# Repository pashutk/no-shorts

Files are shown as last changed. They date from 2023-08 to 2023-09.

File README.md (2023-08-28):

# USB-C Soldering Inspection Hat for Pi Pico

This repository contains a KiCad project for a Raspberry Pi Pico hat. The primary function of this device is to aid in the assessment of soldered USB-C connectors by identifying potential shorts. It offers a practical solution for those requiring a methodical approach to verify the integrity of their soldered USB-C connections.



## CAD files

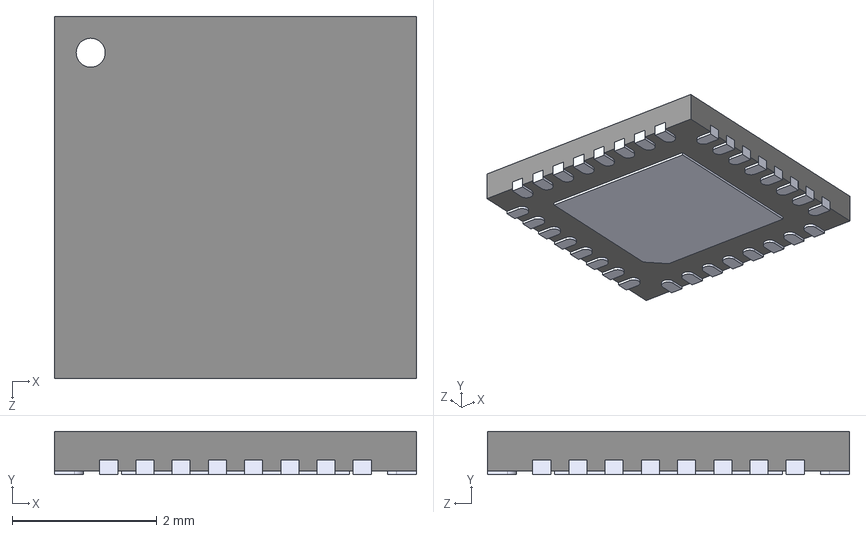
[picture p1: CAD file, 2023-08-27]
3d/TCA6424ARGJR.step
5.00 x 0.6 x 5.00 mm

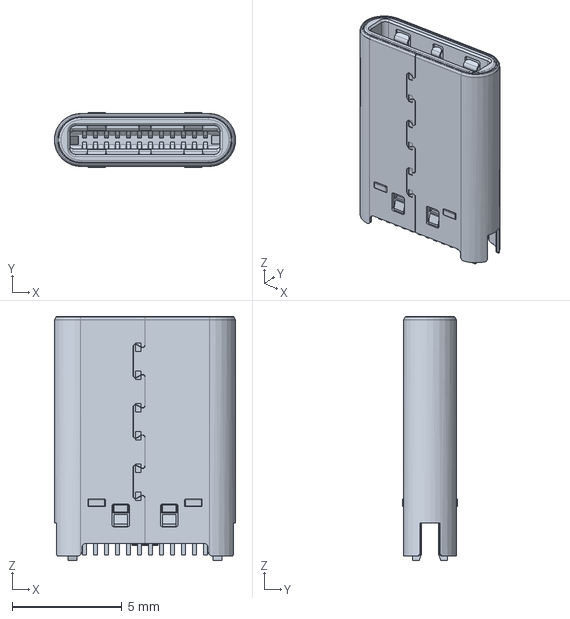
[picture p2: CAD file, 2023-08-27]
3d/CX60-24S-UNIT.step
8.25 x 2.52 x 11.1 mm

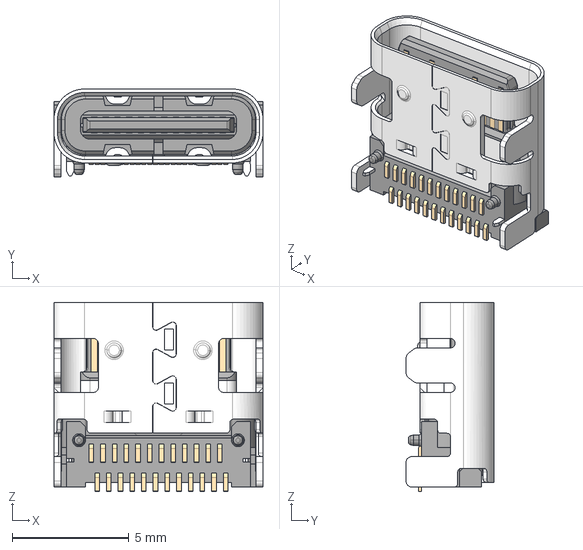
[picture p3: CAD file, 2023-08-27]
3d/USB4080-03-A_REVA1.step
8.94 x 3.76 x 8.10 mm

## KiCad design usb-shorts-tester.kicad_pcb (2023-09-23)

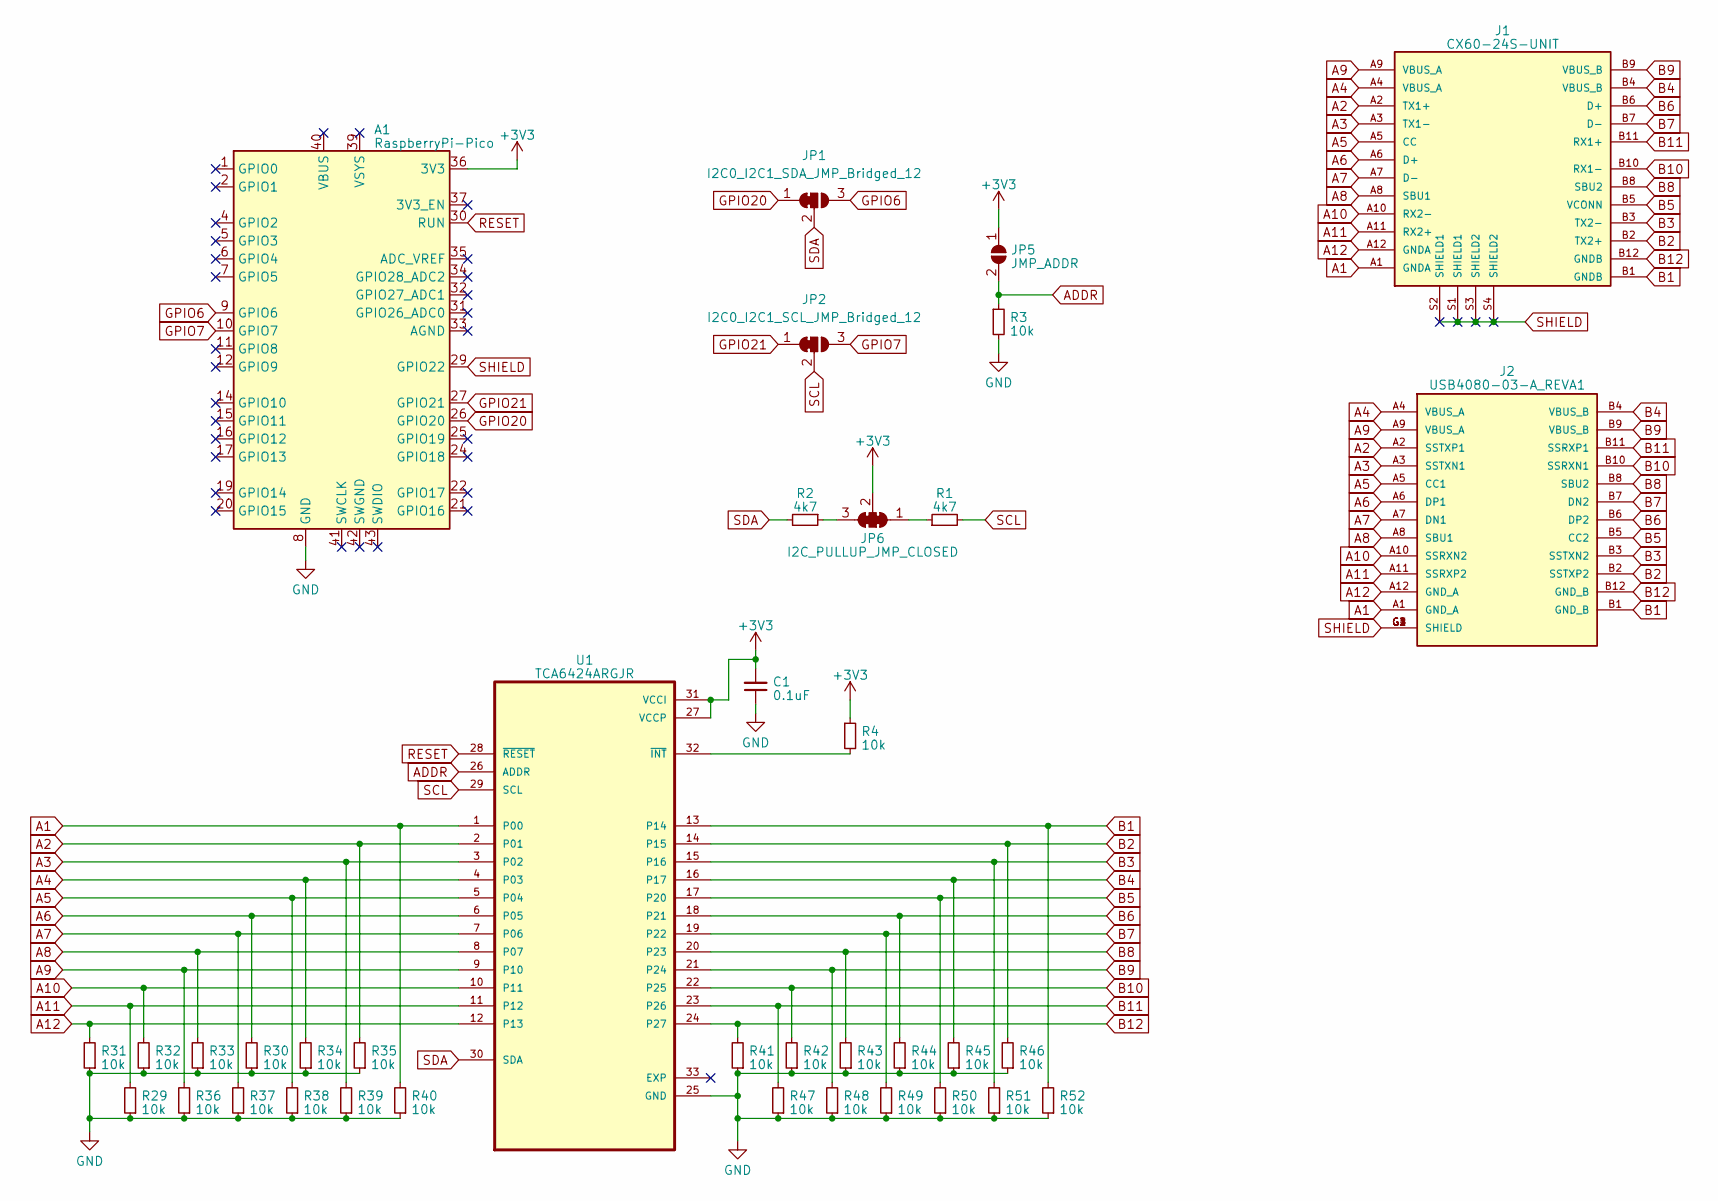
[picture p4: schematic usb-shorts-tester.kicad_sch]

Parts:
A1: RaspberryPi-Pico; Pi_Pico_AddOn
C1: 0.1uF; C_0603_1608Metric
J1: CX60-24S-UNIT; HIROSE_CX60-24S-UNIT; PARTREV 5
J2: USB4080-03-A_REVA1; GCT_USB4080-03-A_REVA1; PARTREV A1
JP1: I2C0_I2C1_SDA_JMP_Bridged_12; SolderJumper-3_P1.3mm_Bridged12_RoundedPad1.0x1.5mm
JP2: I2C0_I2C1_SCL_JMP_Bridged_12; SolderJumper-3_P1.3mm_Bridged12_RoundedPad1.0x1.5mm
JP5: JMP_ADDR; SolderJumper-2_P1.3mm_Open_RoundedPad1.0x1.5mm
JP6: I2C_PULLUP_JMP_CLOSED; SolderJumper-3_P1.3mm_Bridged12_RoundedPad1.0x1.5mm
R1, R2: 4k7; R_0603_1608Metric
R3, R4, R29, R30, R31, R32, R33, R34, R35, R36, R37, R38, R39, R40, R41, R42, R43, R44, R45, R46, R47, R48, R49, R50, R51, R52: 10k; R_0603_1608Metric
U1: TCA6424ARGJR; QFN50P500X500X60-33N

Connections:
+3V3: A1.36 (3V3), C1.2, JP5.1 (A), JP6.2 (C), R4.1, U1.27 (VCCP), U1.31 (VCCI)
A1: J1.A1 (GNDA), J2.A1 (GND_A), R40.2, U1.1 (P00)
A2: J1.A2 (TX1+), J2.A2 (SSTXP1), R35.2, U1.2 (P01)
A3: J1.A3 (TX1-), J2.A3 (SSTXN1), R39.2, U1.3 (P02)
A4: J1.A4 (VBUS_A), J2.A4 (VBUS_A), R34.2, U1.4 (P03)
A5: J1.A5 (CC), J2.A5 (CC1), R38.2, U1.5 (P04)
A6: J1.A6 (D+), J2.A6 (DP1), R30.2, U1.6 (P05)
A7: J1.A7 (D-), J2.A7 (DN1), R37.2, U1.7 (P06)
A8: J1.A8 (SBU1), J2.A8 (SBU1), R33.2, U1.8 (P07)
A9: J1.A9 (VBUS_A), J2.A9 (VBUS_A), R36.2, U1.9 (P10)
A10: J1.A10 (RX2-), J2.A10 (SSRXN2), R32.2, U1.10 (P11)
A11: J1.A11 (RX2+), J2.A11 (SSRXP2), R29.2, U1.11 (P12)
A12: J1.A12 (GNDA), J2.A12 (GND_A), R31.2, U1.12 (P13)
ADDR: JP5.2 (B), R3.1, U1.26 (ADDR)
B1: J1.B1 (GNDB), J2.B1 (GND_B), R52.2, U1.13 (P14)
B2: J1.B2 (TX2+), J2.B2 (SSTXP2), R46.2, U1.14 (P15)
B3: J1.B3 (TX2-), J2.B3 (SSTXN2), R51.2, U1.15 (P16)
B4: J1.B4 (VBUS_B), J2.B4 (VBUS_B), R45.2, U1.16 (P17)
B5: J1.B5 (VCONN), J2.B5 (CC2), R50.2, U1.17 (P20)
B6: J1.B6 (D+), J2.B6 (DP2), R44.2, U1.18 (P21)
B7: J1.B7 (D-), J2.B7 (DN2), R49.2, U1.19 (P22)
B8: J1.B8 (SBU2), J2.B8 (SBU2), R43.2, U1.20 (P23)
B9: J1.B9 (VBUS_B), J2.B9 (VBUS_B), R48.2, U1.21 (P24)
B10: J1.B10 (RX1-), J2.B10 (SSRXN1), R42.2, U1.22 (P25)
B11: J1.B11 (RX1+), J2.B11 (SSRXP1), R47.2, U1.23 (P26)
B12: J1.B12 (GNDB), J2.B12 (GND_B), R41.2, U1.24 (P27)
GND: A1.3 (GND), A1.8 (GND), A1.13 (GND), A1.18 (GND), A1.23 (GND), A1.28 (GND), A1.38 (GND), C1.1, R3.2, R29.1, R30.1, R31.1, R32.1, R33.1, R34.1, R35.1, R36.1, R37.1, R38.1, R39.1, R40.1, R41.1, R42.1, R43.1, R44.1, R45.1, R46.1, R47.1, R48.1, R49.1, R50.1, R51.1, R52.1, U1.25 (GND)
GPIO6: A1.9 (GPIO6), JP1.3 (B)
GPIO7: A1.10 (GPIO7), JP2.3 (B)
GPIO20: A1.26 (GPIO20), JP1.1 (A)
GPIO21: A1.27 (GPIO21), JP2.1 (A)
unnamed: JP6.1 (A), R1.1
unnamed: JP6.3 (B), R2.1
unnamed: R4.2, U1.32 (~INT)
RESET: A1.30 (RUN), U1.28 (~RESET)
SCL: JP2.2 (C), R1.2, U1.29 (SCL)
SDA: JP1.2 (C), R2.2, U1.30 (SDA)
SHIELD: A1.29 (GPIO22), J1.S1 (SHIELD1), J1.S2 (SHIELD1), J1.S3 (SHIELD2), J1.S4 (SHIELD2), J2.G1 (SHIELD), J2.G2 (SHIELD), J2.G3 (SHIELD), J2.G4 (SHIELD)

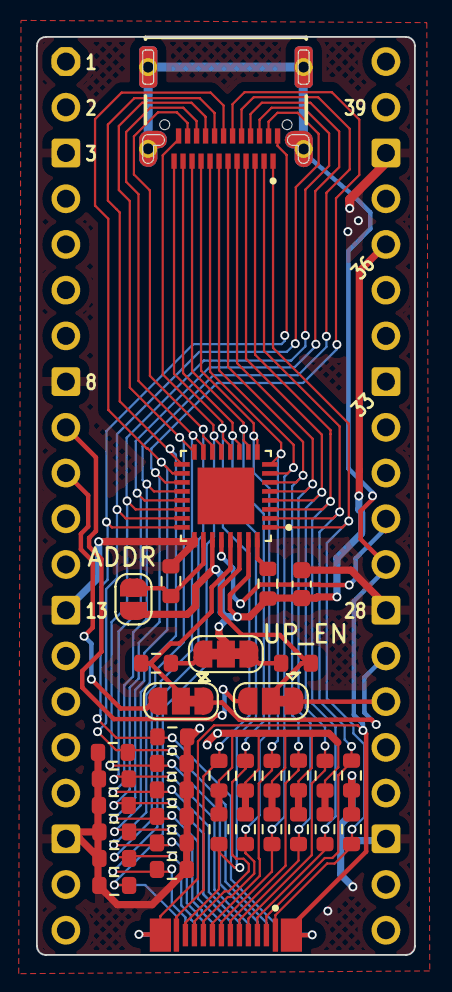
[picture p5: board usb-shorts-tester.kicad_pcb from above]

Board: 2 copper layers, 21.0 x 51.0 mm, 37 parts (0 on the bottom side), 38 nets.

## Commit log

2023-08-28 Beta release
    [usb-shorts-tester.kicad_pcb, usb-shorts-tester.kicad_sch]
2023-09-03 Add usb shield probing
    [usb-shorts-tester.kicad_pcb, usb-shorts-tester.kicad_sch]
2023-09-23 Add pulldowns on all expander pins
    [usb-shorts-tester.kicad_pcb, usb-shorts-tester.kicad_sch]
